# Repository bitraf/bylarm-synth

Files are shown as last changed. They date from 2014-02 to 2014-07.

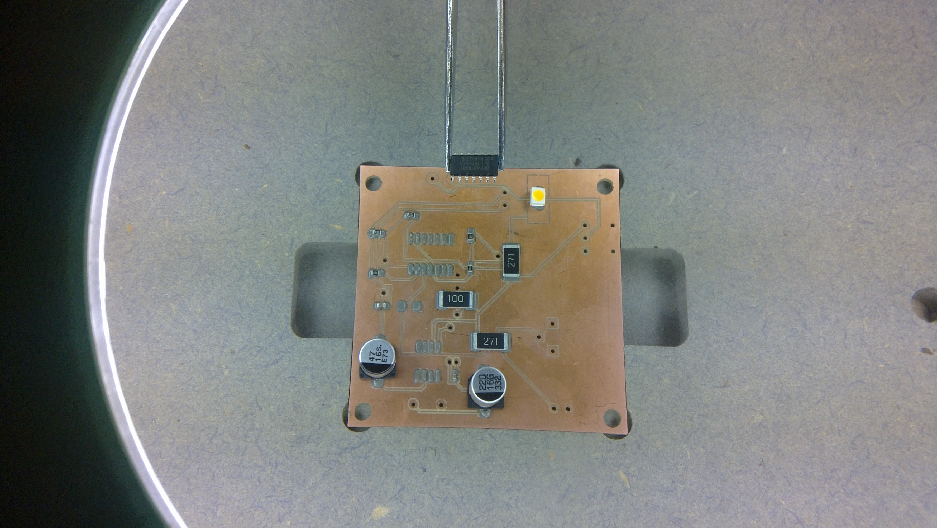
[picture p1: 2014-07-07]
doc/images/bitraf-bylarm2014-placing-components.jpg

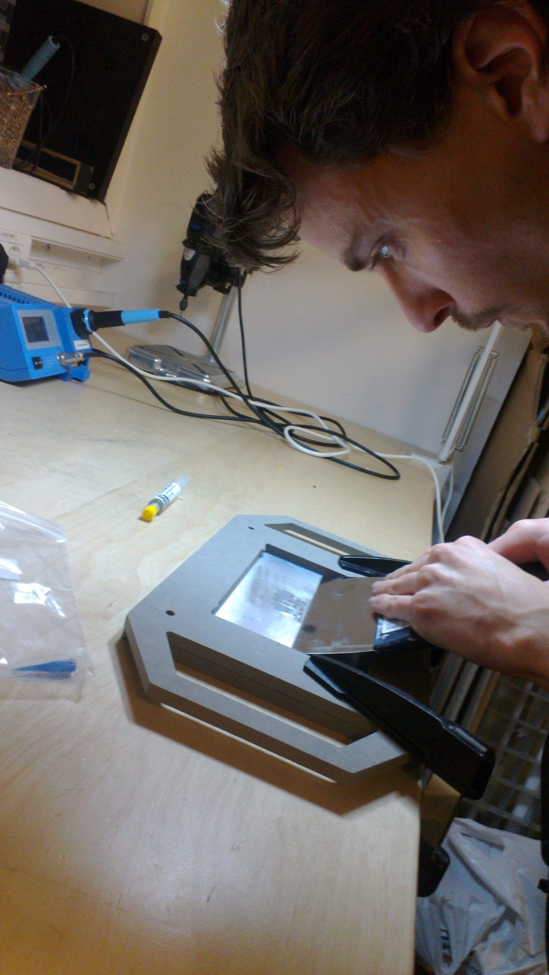
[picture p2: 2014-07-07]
doc/images/bitraf-bylarm2014-jens-solderpaste.jpg

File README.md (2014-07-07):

This is an analog synthesier, designed to be built as a 3-hour workshop by people new to electronics.
Made for [By:larm](http://www.bylarm.no/) Interactive in Oslo, 2014.

The project consists of both electronics, casing and tooling for applying solder paste. The project was produced on a standard Shopbot.
The electronics is mostly surface-mount technology and designed to be soldered using a reflow oven.

Credits
========
* Vidar Kristiansen
* [Jens Dyvik](http://dyvikdesign.com)
* Thomas Winther
* [Jon Nordby](http://jonnor.com)

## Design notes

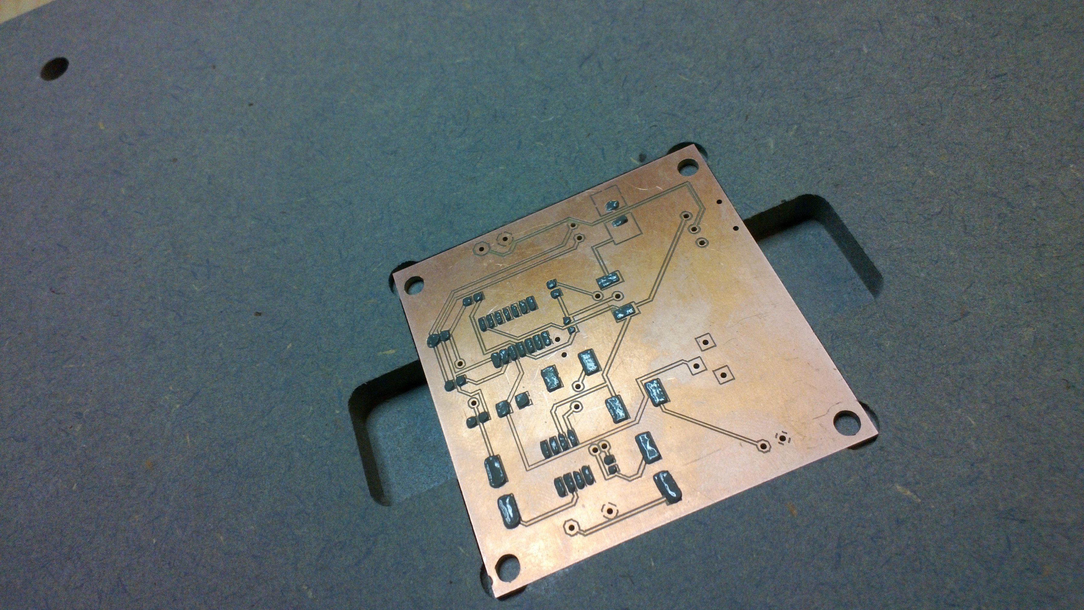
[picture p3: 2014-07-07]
doc/images/bitraf-bylarm2014-board-with-paste.jpg

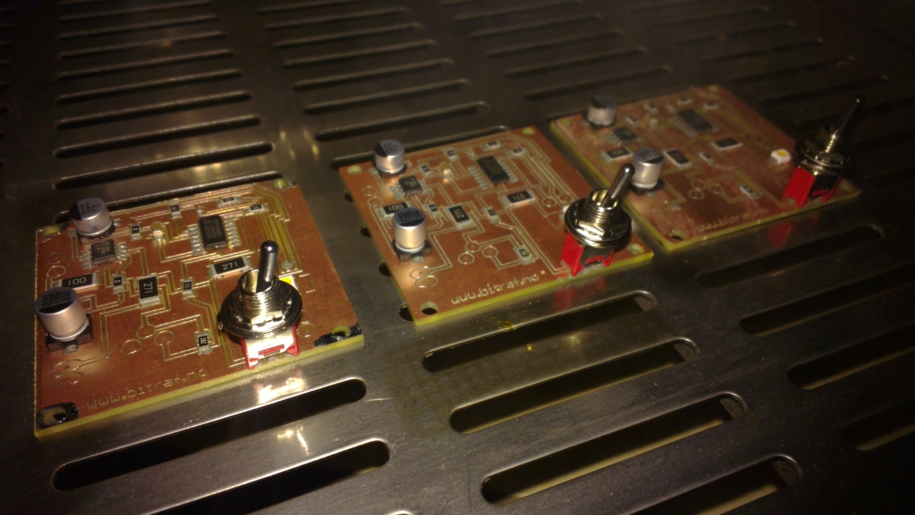
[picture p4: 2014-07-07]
doc/images/bitraf-bylarm2014-boards-in-oven.jpg

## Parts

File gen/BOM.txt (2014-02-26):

Part   Value        Package      Description                          
C1     47 µF        CLV-0605     POLARIZED CAPACITOR 
C2     220 µf       CLV-0605     POLARIZED CAPACITOR 
C3     47 nF        C0402        CAPACITOR           
C7     1 µF         C0603        CAPACITOR           
C8     10 µF        C1206        CAPACITOR           
IC1    LM386M-1     SO08         Low Voltage Audio Power Amplifier    
IC2    40106        SO14         Hex SCHMITT TRIGGER                  
LED1                LED3MM       LED 3mm                                 
LED2                SMD          LED                                  
R1     10 Ω         R2512        RESISTOR            
R2     150 Ω        R1206        RESISTOR            
R3     1,8 kΩ       R1206        RESISTOR            
R4     LDR 1MΩ      0204V        RESISTOR            
R5     270Ω         R2512        RESISTOR            
R6     270Ω         R2512        RESISTOR            
R8     100 Ω        R1206        RESISTOR            
R9     0Ω           R1206        RESISTOR            
R10    0Ω           R1206        RESISTOR            
R12    10 kΩ        R1206        RESISTOR            
R13    10 kΩ        R1206        RESISTOR                                                 
U$1    SMALLPOT     SMALLPOT           SMALLPOT                                          
U$2    BYLARMSWITCH BYLARMSWITCH       BYLARMSWITCH                                      
VBATT
SPKR

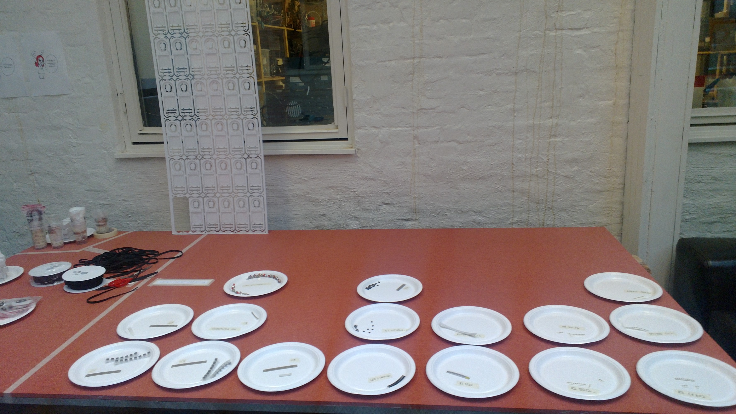
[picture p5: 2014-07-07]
doc/images/bitraf-bylarm2014-components-ready.jpg

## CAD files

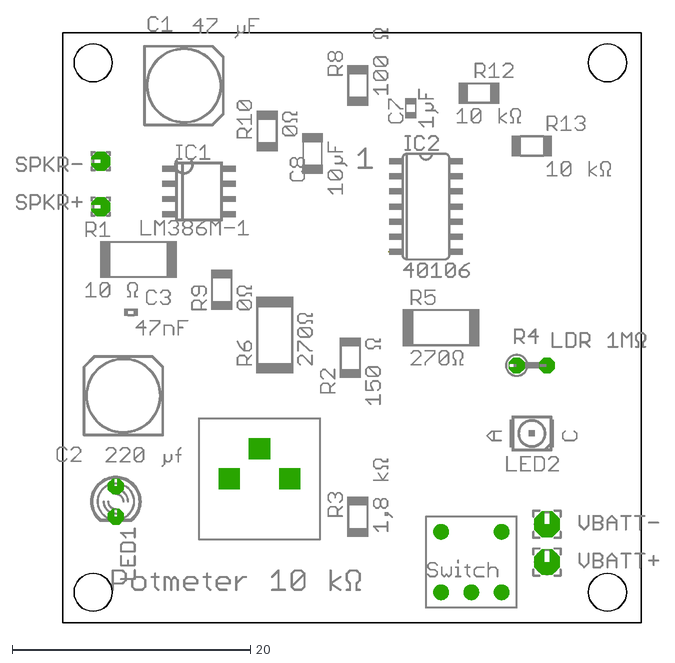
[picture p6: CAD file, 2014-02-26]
gen/outline.dxf
54.0 x 50.9

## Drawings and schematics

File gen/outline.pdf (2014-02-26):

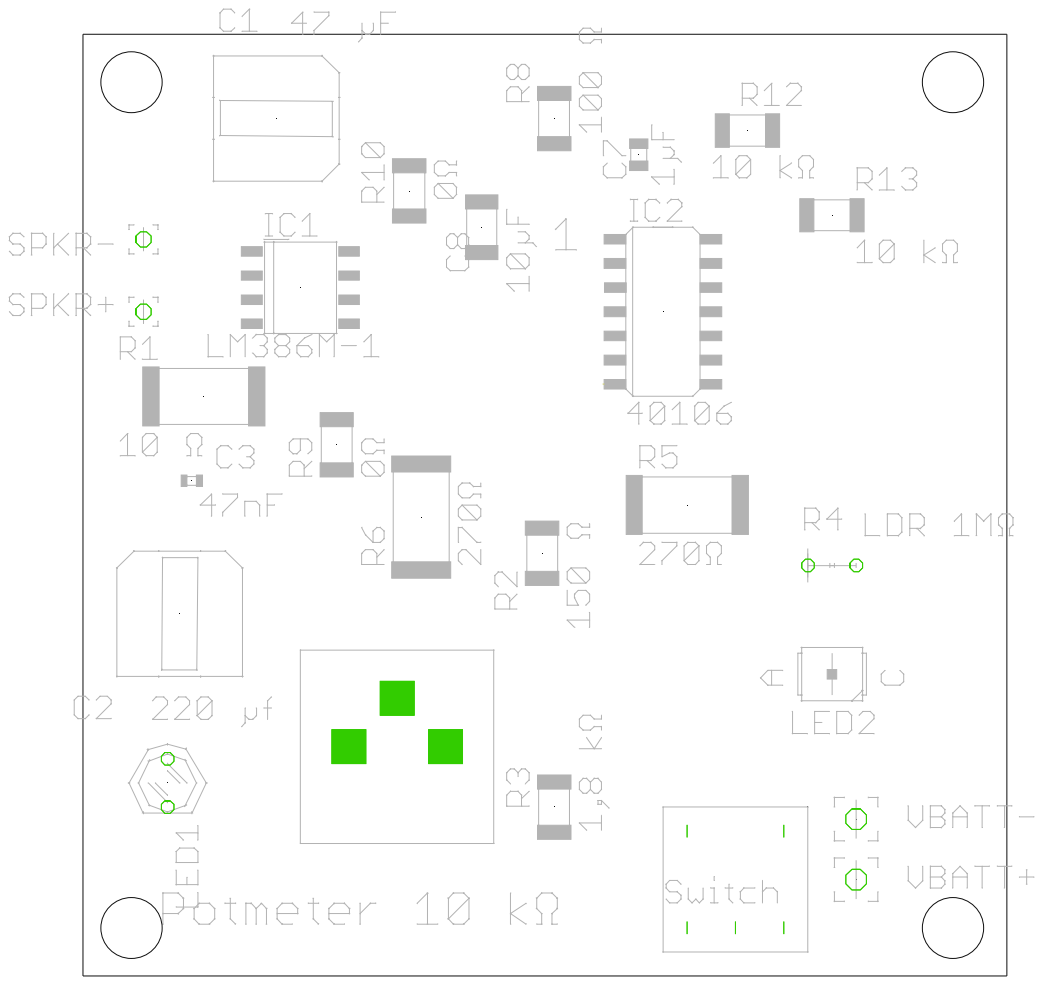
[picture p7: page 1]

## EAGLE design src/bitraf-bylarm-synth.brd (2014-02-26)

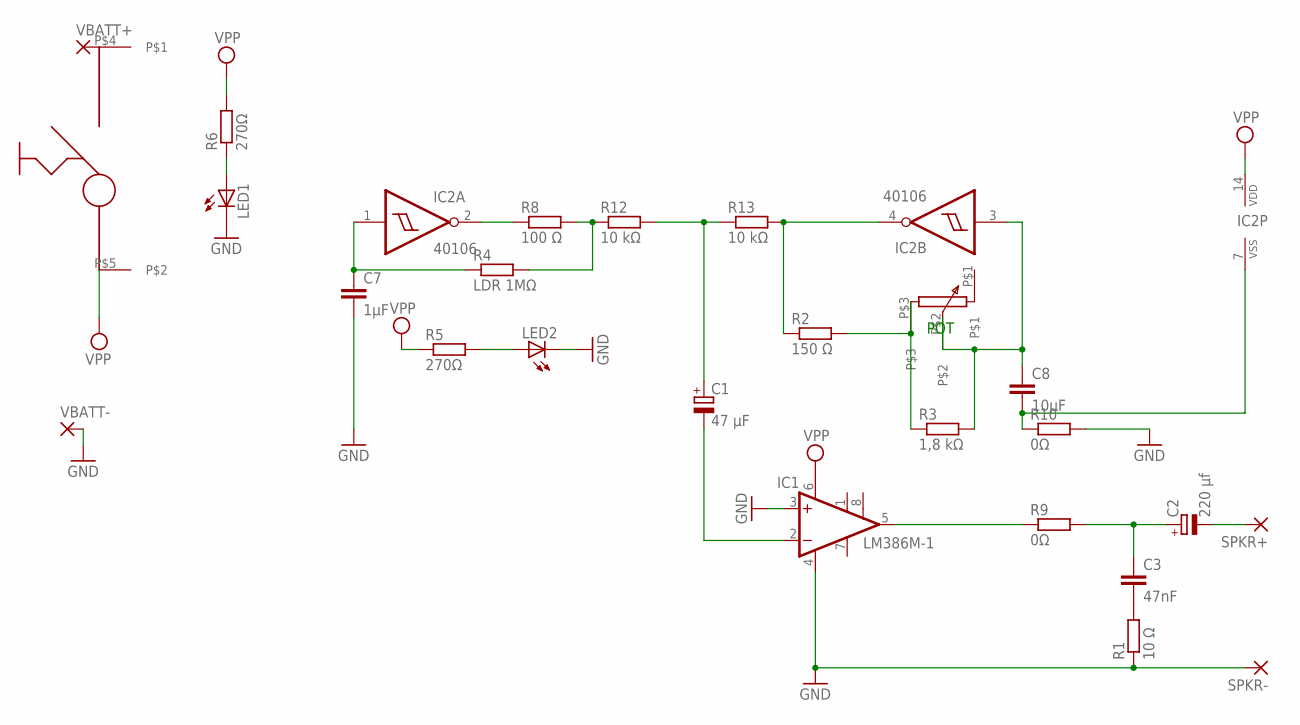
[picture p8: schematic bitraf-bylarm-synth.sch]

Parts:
C1: 47 µF; 153CLV-0605
C2: 220 µf; 153CLV-0605
C3: 47nF; C0402
C7: 1µF; C0603
C8: 10µF; C1206
IC1: LM386M-1; SO08
IC2: 40106; SO14
LED1: LED3MM
LED2: LEDP-LCC-2; P-LCC-2
R1: 10 Ω; R2512
R2: 150 Ω; R1206
R3: 1,8 kΩ; R1206
R4: LDR 1MΩ; 0204V
R5, R6: 270Ω; R2512
R8: 100 Ω; R1206
R9, R10: 0Ω; R1206
R12, R13: 10 kΩ; R1206
SPKR+: 1,6/0,9
SPKR-: 1,6/0,9
U$1: SMALLPOT
U$2: BYLARMSWITCH
VBATT+: 2,15/1,0
VBATT-: 2,15/1,0

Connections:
GND: C7.2, IC1.3 (+IN), IC1.4 (GND), LED1.K (C), LED2.C, R1.1, R10.2, SPKR-.1, VBATT-.1
unnamed: R4.2, R8.2, R12.1
unnamed: C2.+, C3.1, R9.2
unnamed: C1.-, IC1.2 (-IN)
unnamed: C3.2, R1.2
unnamed: R2.2, R3.1, U$1.P$3
unnamed: C8.1, IC2.3 (I), R3.2, U$1.P$2
unnamed: LED1.A, R6.1
unnamed: LED2.A, R5.2
unnamed: U$2.P$4, VBATT+.1
unnamed: C1.+, R12.2, R13.1
unnamed: C7.1, IC2.1 (I), R4.1
unnamed: C8.2, IC2.7 (VSS), R10.1
unnamed: IC1.5 (OUT), R9.1
unnamed: IC2.2 (O), R8.1
unnamed: IC2.4 (O), R2.1, R13.2
SPKR+: C2.-, SPKR+.1
VPP: IC1.6 (VS), IC2.14 (VDD), R5.1, R6.2, U$2.P$5

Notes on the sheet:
POT

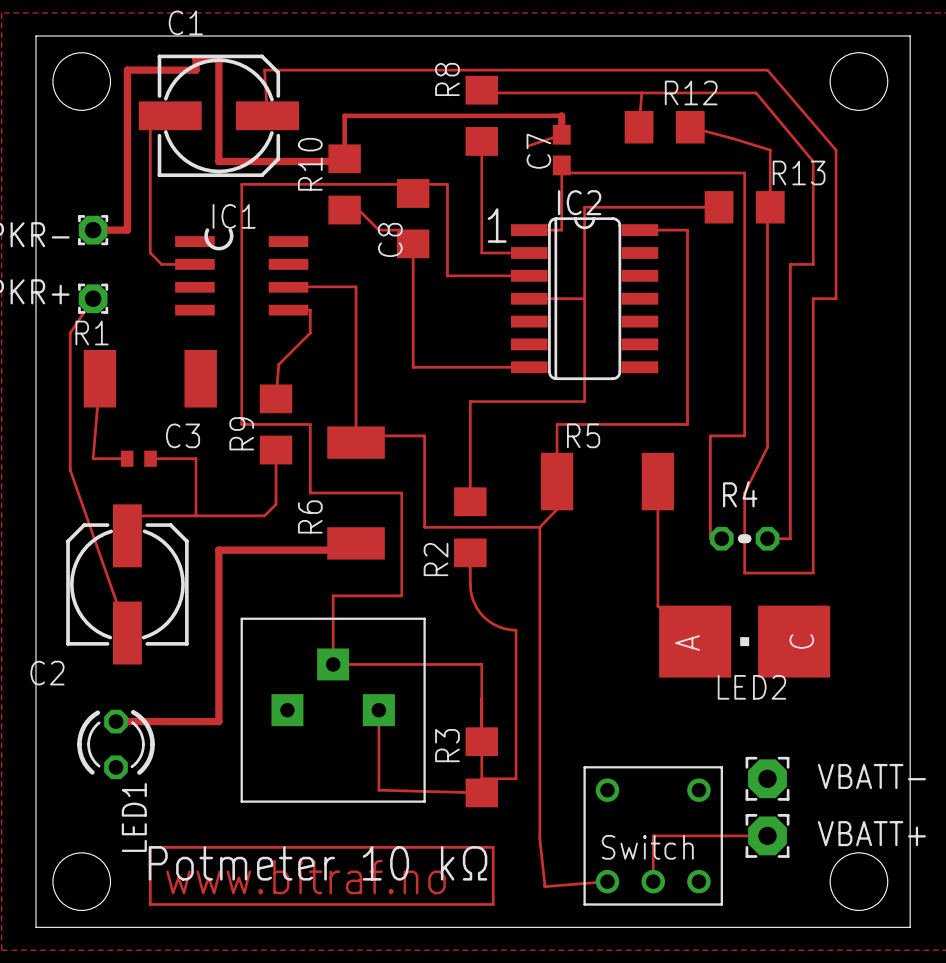
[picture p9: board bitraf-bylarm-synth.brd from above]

Board: 2 copper layers, 48.6 x 49.5 mm, 26 parts (0 on the bottom side), 18 nets.

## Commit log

2014-02-25 Initial commitˍ
2014-02-25 Add Eagle project files for latest revisionx
    [bitraf-bylarm-synth.brd, bitraf-bylarm-synth.sch]
2014-02-26 Tweak schematics and layout for actual values used
    [bitraf-bylarm-synth.brd, bitraf-bylarm-synth.sch]
2014-02-26 Add BOM list
2014-02-26 Add component outlines
    [outline.dxf]
